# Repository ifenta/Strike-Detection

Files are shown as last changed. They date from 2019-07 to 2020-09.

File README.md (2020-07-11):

# Strike-Detection
Ideally I want to be able to:
- correct different strike and block techniques
- calculate speed of the strikes
- count how many times you do different strikes (flow hitting on a heavy bag for example)

With the camera, I want: 
- correct form now that I can see the whole body and depth
- detect if you are doing a lead or rear punch/kick
- see if I can improve transitions from different techniques

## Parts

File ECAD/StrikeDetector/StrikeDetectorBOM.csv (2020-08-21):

Qty | Value | Device | Package | Parts | Description
1 |  | CP2104-F03-GM | QFN50P400X400X80-25N | U5 | USB-to-UART 1-CH 576byte FIFO 3.3V 24-Pin QFN EP T/R
1 |  | HEADER-1X2ROUND | 1X02_ROUND | JP1 | PIN HEADER
1 |  | HEADER-1X6ROUND | 1X06_ROUND | JP3 | PIN HEADER
1 | 0.22uF | CAP_CERAMIC0603 | 0603 | C2 | Ceramic Capacitors
4 | 100kΩ | RESISTOR0603 | 0603 | R1, R2, R5, R11 | Resistors
1 | 10118193-0001LF | 10118193-0001LF | FCI_10118193-0001LF | J1 | Micro USB B Type Receptacle
2 | 10kΩ | RESISTOR0603 | 0603 | R3, R4 | Resistors
6 | 10uF | CAP_CERAMIC0603 | 0603 | C1, C3, C4, C6, C7, C8 | Ceramic Capacitors
2 | 1kΩ | RESISTOR0603 | 0603 | R9, R10 | Resistors
1 | 1uF | CAP_CERAMIC0603 | 0603 | C5 | Ceramic Capacitors
3 | 4.7kΩ | RESISTOR0603 | 0603 | R6, R7, R8 | Resistors
1 | AP2112K-3.3TRG1 | AP2112K-3.3TRG1 | SOT95P285X140-5N | U6 | AP2112 Series 0.6 A 3.3 V Fixed Output SMT LDO Linear Regulator - SOT23-5
1 | CJS-1200TA | CJS-1200TA | SW_CJS-1200TA | S1 | Switch Slide N.O./N.C. SPDT Raised Slide 0.1A 24VDC J-Hook SMD Embossed T/R
1 | ESP32-WROOM-32 | ESP32-WROOM-32 | MODULE_ESP32-WROOM-32 | U4 | Bluetooth, WiFi Transceiver Module 2.4GHz ~ 2.5GHz Surface Mount
2 | KMR211GLFS | SPST_TACT-KMR2 | KMR2 | SW1, SW2 | SMT 6mm switch, EVQQ2 series
1 | LSM9DS1TR | LSM9DS1TR | PQFN43P300X350X102-24N | U3 | The LSM9DS1 is a system-in-package featuring a
2 | MBR120 | DIODESOD-123 | SOD-123 | D1, D2 | Diode
1 | MCP73831T-2ACI/OT | MCP73831T-2ACI/OT | SOT95P280X145-5N | U$1 | Charge Management Controller
2 | MMBT2222A-7-F | MMBT2222A-7-F | SOT103P240X110-3N | U1, U2 | NPN SMALL SIGNAL SURFACE MOUNT TRANSISTOR
1 | ORANGE | LED0603 | CHIPLED_0603 | LED2 | LED
1 | RED | LED0603 | CHIPLED_0603 | LED1 | LED

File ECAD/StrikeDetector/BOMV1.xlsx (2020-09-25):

Designator | MPN | Qty | Link
C1, C3, C4, C6, C7, C8 | LMK107BBJ106MALT | 6 | https://www.digikey.com/product-detail/en/taiyo-yuden/LMK107BBJ106MALT/587-3258-1-ND/3662218
C2 | CC0603KRX7R7BB224 | 1 | https://www.digikey.com/product-detail/en/yageo/CC0603KRX7R7BB224/311-1426-1-ND/2833732
C5 | CL10B105MO8NNWC | 1 | https://www.digikey.com/product-detail/en/samsung-electro-mechanics/CL10B105MO8NNWC/1276-6524-1-ND/5961383
D1, D2 | MBR120ESFT3G | 2 | https://www.digikey.com/product-detail/en/on-semiconductor/MBR120ESFT3G/MBR120ESFT3GOSCT-ND/5969071
J1 | 10118193-0001LF | 1 | https://www.digikey.com/product-detail/en/amphenol-icc-fci/10118193-0001LF/609-4616-1-ND/2785380
LED1 | 150060RS75000 | 1 | https://www.digikey.com/product-detail/en/w%C3%BCrth-elektronik/150060RS75000/732-4978-1-ND/4489899
LED2 | 150060YS75000 | 1 | https://www.digikey.com/product-detail/en/w%C3%BCrth-elektronik/150060YS75000/732-4981-1-ND/4489907
R1, R2, R5, R11 | RMCF0603FT100K | 4 | https://www.digikey.com/product-detail/en/stackpole-electronics-inc/RMCF0603FT100K/RMCF0603FT100KCT-ND/1943118
R3, R4, R6, R7, R8, R12, R13, R14, R15, R16 | RC0603FR-0710KL | 10 | https://www.digikey.com/product-detail/en/yageo/RC0603FR-0710KL/311-10-0KHRCT-ND/729827
R9, R10 | RC0603FR-071KL | 2 | https://www.digikey.com/product-detail/en/yageo/RC0603FR-071KL/311-1-00KHRCT-ND/729790
S1 | CJS-1200TA | 1 | https://www.digikey.com/product-detail/en/nidec-copal-electronics/CJS-1200TA/563-1021-1-ND/948401
SW1, SW2 | KMR211GLFS | 2 | https://www.digikey.com/product-detail/en/c-k/KMR211GLFS/401-1426-1-ND/550461
U$1 | MCP73831T-2ACI/OT | 1 | https://www.digikey.com/product-detail/en/microchip-technology/MCP73831T-2ACI-OT/MCP73831T-2ACI-OTCT-ND/1979802
U1, U2 | MMBT2222A-7-F | 2 | https://www.digikey.com/product-detail/en/diodes-incorporated/MMBT2222A-7-F/MMBT2222A-FDICT-ND/815723
U3 | LSM9DS1TR | 1 | https://www.digikey.com/product-detail/en/stmicroelectronics/LSM9DS1TR/497-14946-1-ND/4988079
U4 | ESP32-WROOM-32 | 1 | https://www.digikey.com/product-detail/en/espressif-systems/ESP32-WROOM-32/1904-1010-1-ND/8544305
U5 | CP2104-F03-GMR | 1 | https://www.digikey.com/product-detail/en/silicon-labs/CP2104-F03-GMR/336-4146-1-ND/7650425
U6 | AP2112K-3.3TRG1 | 1 | https://www.digikey.com/product-detail/en/diodes-incorporated/AP2112K-3-3TRG1/AP2112K-3-3TRG1DICT-ND/4505257

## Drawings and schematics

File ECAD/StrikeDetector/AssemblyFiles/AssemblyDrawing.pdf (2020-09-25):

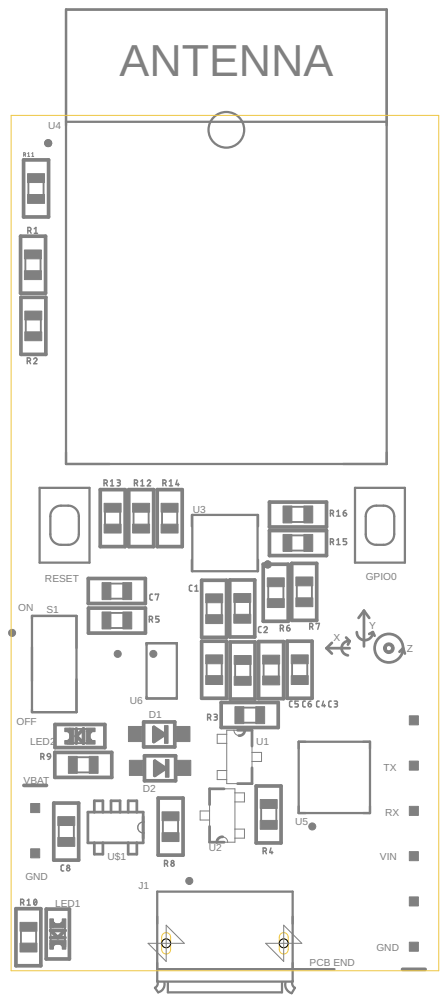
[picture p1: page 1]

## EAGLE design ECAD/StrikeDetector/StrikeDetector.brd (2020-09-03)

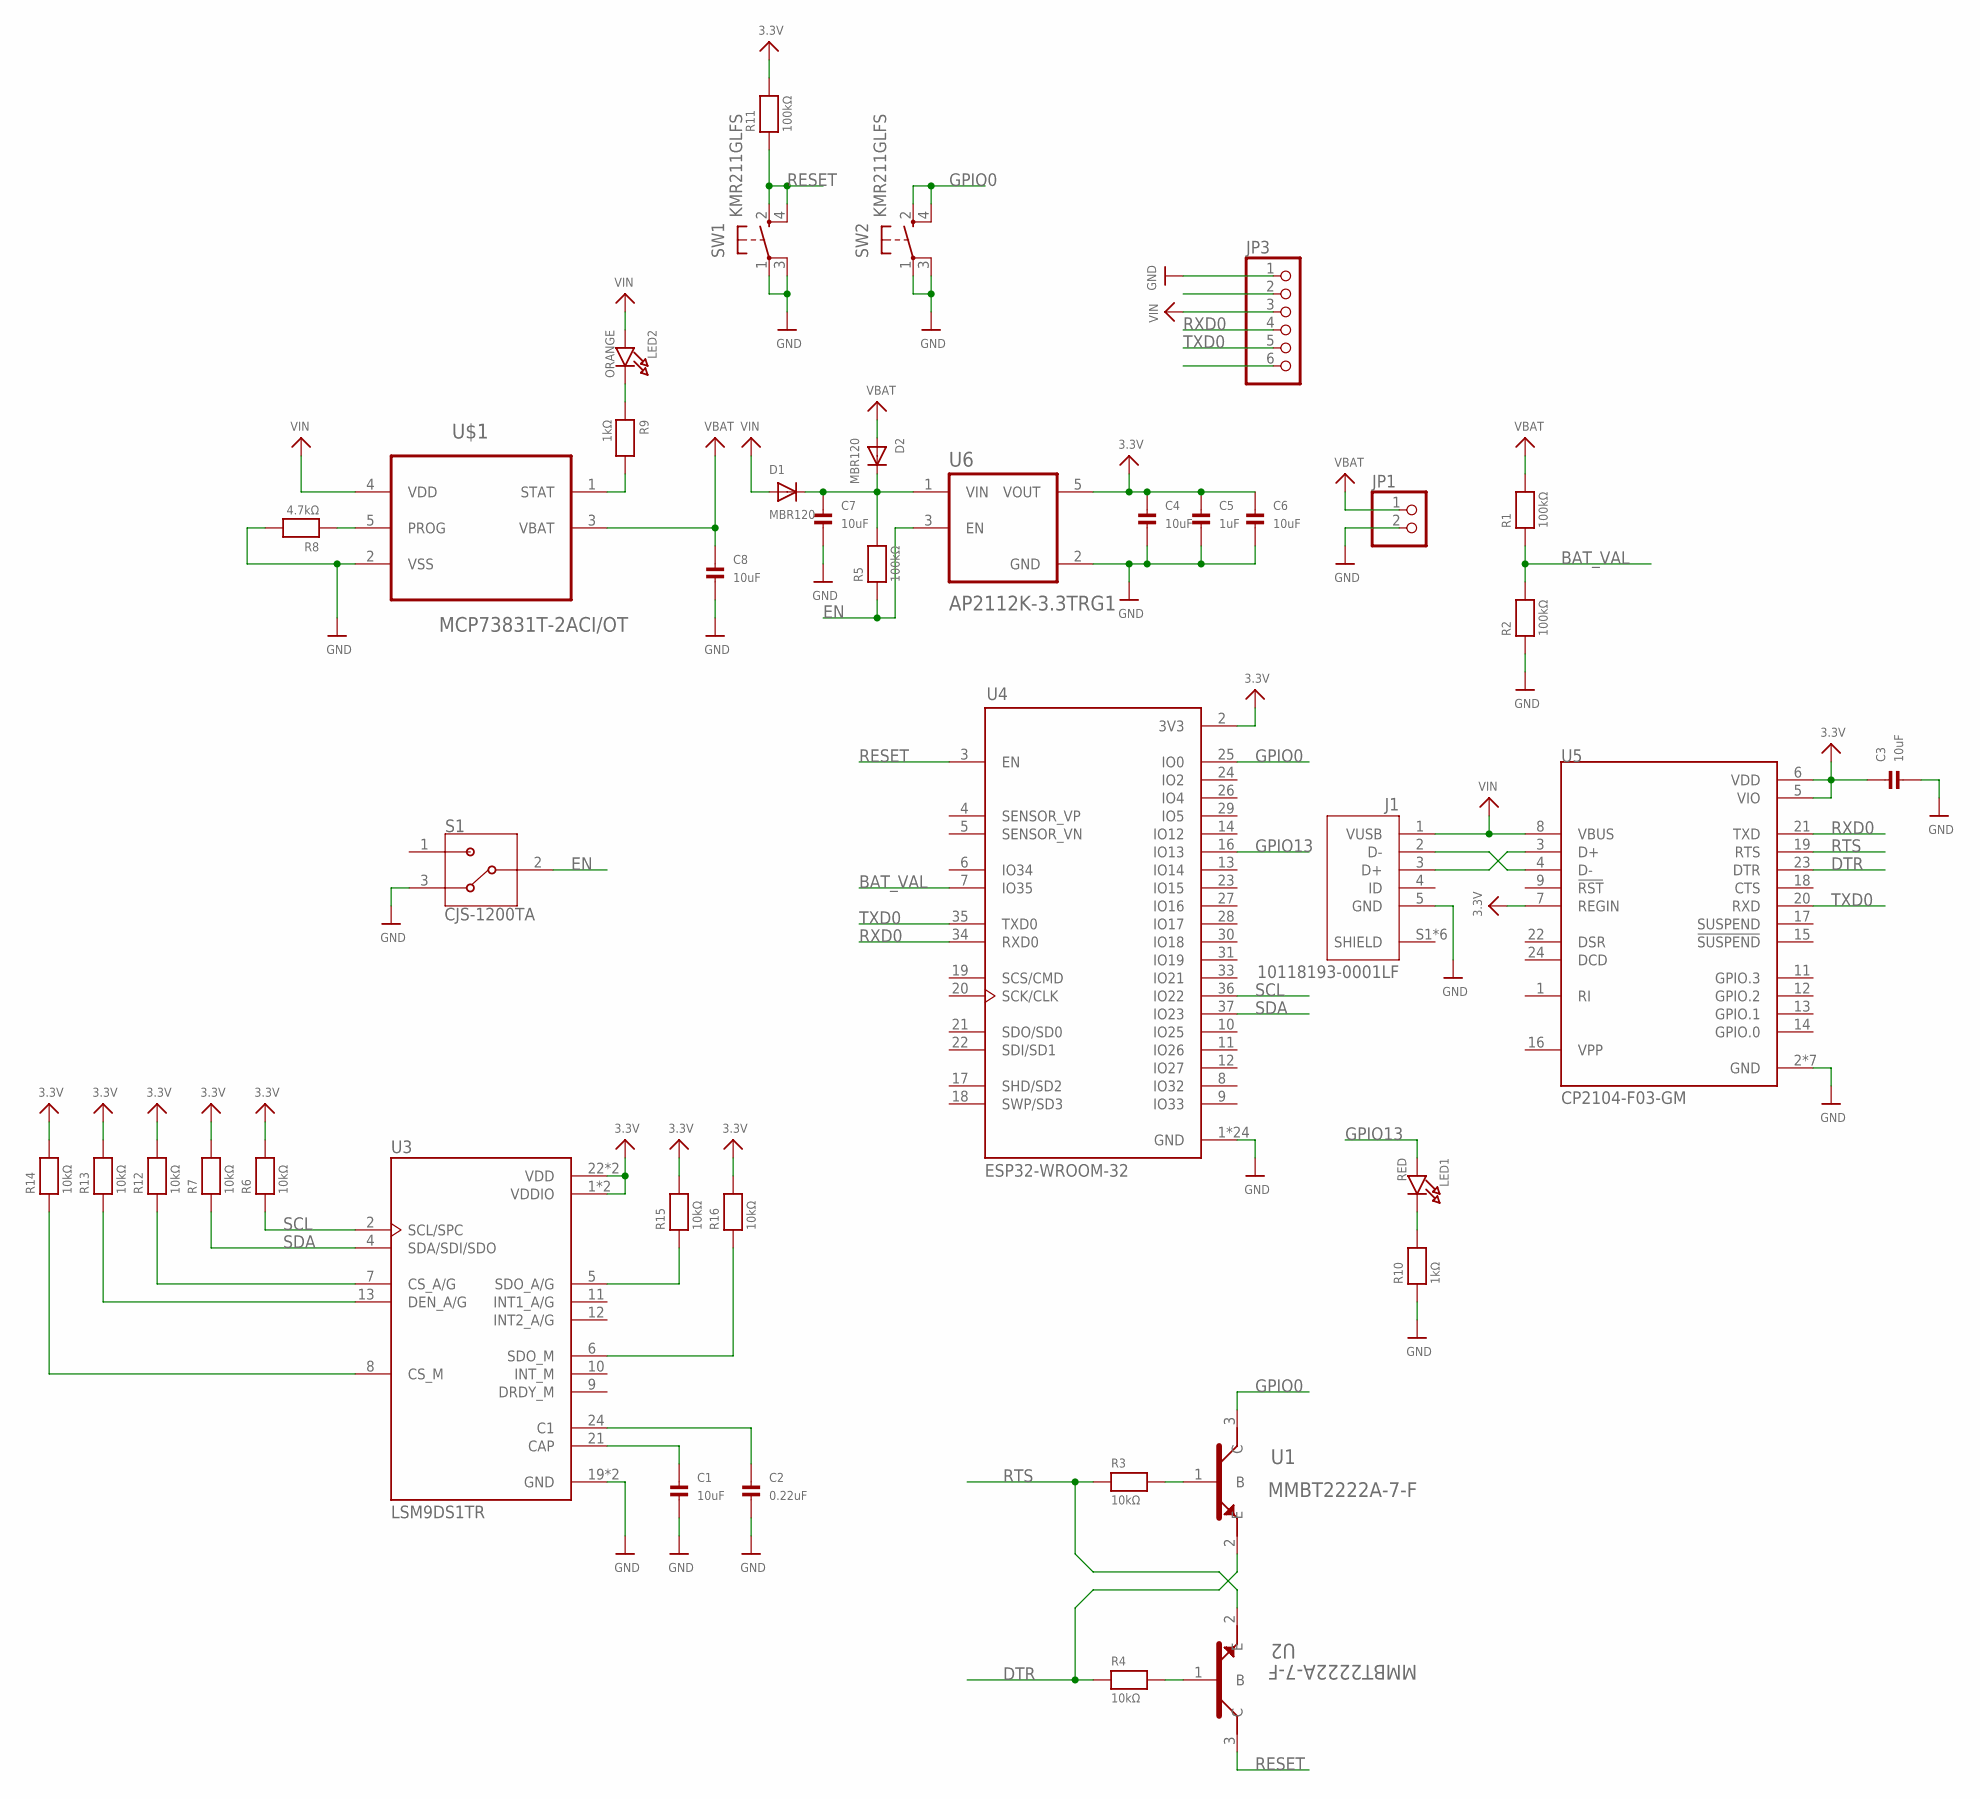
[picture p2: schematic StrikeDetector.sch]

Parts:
C1, C3, C4, C6, C7, C8: 10uF; 0603
C2: 0.22uF; 0603
C5: 1uF; 0603
D1, D2: MBR120; SOD-123
J1: 10118193-0001LF; FCI_10118193-0001LF
JP1: HEADER-1X2ROUND; 1X02_ROUND
JP3: HEADER-1X6ROUND; 1X06_ROUND
LED1: RED; CHIPLED_0603
LED2: ORANGE; CHIPLED_0603
R1, R2, R5, R11: 100kΩ; 0603
R3, R4, R6, R7, R12, R13, R14, R15, R16: 10kΩ; 0603
R8: 4.7kΩ; 0603
R9, R10: 1kΩ; 0603
S1: CJS-1200TA; SW_CJS-1200TA
SW1, SW2: KMR211GLFS; KMR2
U1, U2: MMBT2222A-7-F; SOT103P240X110-3N
U3: LSM9DS1TR; PQFN43P300X350X102-24N
U4: ESP32-WROOM-32; MODULE_ESP32-WROOM-32
U5: CP2104-F03-GM; QFN50P400X400X80-25N
U6: AP2112K-3.3TRG1; SOT95P285X140-5N
U$1: MCP73831T-2ACI/OT; SOT95P280X145-5N

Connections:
3.3V: C3.1, C4.1, C5.1, C6.1, R6.2, R7.2, R11.2, R12.2, R13.2, R14.2, R15.2, R16.2, U3.1 (VDDIO), U3.3 (VDDIO), U3.22 (VDD), U3.23 (VDD), U4.2 (3V3), U5.5 (VIO), U5.6 (VDD), U5.7 (REGIN), U6.5 (VOUT)
BAT_VAL: R1.1, R2.2, U4.7 (IO35)
DTR: R4.1, U1.2 (E), U5.23 (DTR)
EN: R5.1, S1.2, U6.3 (EN)
GND: C1.2, C2.2, C3.2, C4.2, C5.2, C6.2, C7.2, C8.2, J1.5 (GND), JP1.2, JP3.1, R2.1, R8.2, R10.1, S1.3, SW1.1, SW1.3 (P1), SW2.1, SW2.3 (P1), U3.19 (GND), U3.20 (GND), U4.1 (GND), U4.15 (GND), U4.38 (GND), U4.39_1 (GND), U4.39_2 (GND), U4.39_3 (GND), U4.39_4 (GND), U4.39_5 (GND), U4.39_6 (GND), U4.39_7 (GND), U4.39_8 (GND), U4.39_9 (GND), U4.39_10 (GND), U4.39_11 (GND), U4.39_12 (GND), U4.39_13 (GND), U4.39_14 (GND), U4.39_15 (GND), U4.39_16 (GND), U4.39_17 (GND), U4.39_18 (GND), U4.39_19 (GND), U4.39_20 (GND), U4.39_21 (GND), U5.2 (GND), U5.25 (GND), U5.THERM_1 (GND), U5.THERM_2 (GND), U5.THERM_3 (GND), U5.THERM_4 (GND), U5.THERM_5 (GND), U6.2 (GND), U$1.2 (VSS)
GPIO0: SW2.2 (S), SW2.4 (S1), U1.3 (C), U4.25 (IO0)
GPIO13: LED1.A, U4.16 (IO13)
unnamed: C1.1, U3.21 (CAP)
unnamed: J1.3 (D+), U5.3 (D+)
unnamed: J1.2 (D-), U5.4 (D-)
unnamed: C2.1, U3.24 (C1)
unnamed: R3.2, U1.1 (B)
unnamed: R4.2, U2.1 (B)
unnamed: C7.1, D1.C, D2.C, R5.2, U6.1 (VIN)
unnamed: R8.1, U$1.5 (PROG)
unnamed: R9.2, U$1.1 (STAT)
unnamed: LED2.C, R9.1
unnamed: LED1.C, R10.2
unnamed: R12.1, U3.7 (CS_A/G)
unnamed: R13.1, U3.13 (DEN_A/G)
unnamed: R14.1, U3.8 (CS_M)
unnamed: R15.1, U3.5 (SDO_A/G)
unnamed: R16.1, U3.6 (SDO_M)
RESET: R11.1, SW1.2 (S), SW1.4 (S1), U2.3 (C), U4.3 (EN)
RTS: R3.1, U2.2 (E), U5.19 (RTS)
RXD0: JP3.4, U4.34 (RXD0), U5.21 (TXD)
SCL: R6.1, U3.2 (SCL/SPC), U4.36 (IO22)
SDA: R7.1, U3.4 (SDA/SDI/SDO), U4.37 (IO23)
TXD0: JP3.5, U4.35 (TXD0), U5.20 (RXD)
VBAT: C8.1, D2.A, JP1.1, R1.2, U$1.3 (VBAT)
VIN: D1.A, J1.1 (VUSB), JP3.3, LED2.A, U5.8 (VBUS), U$1.4 (VDD)

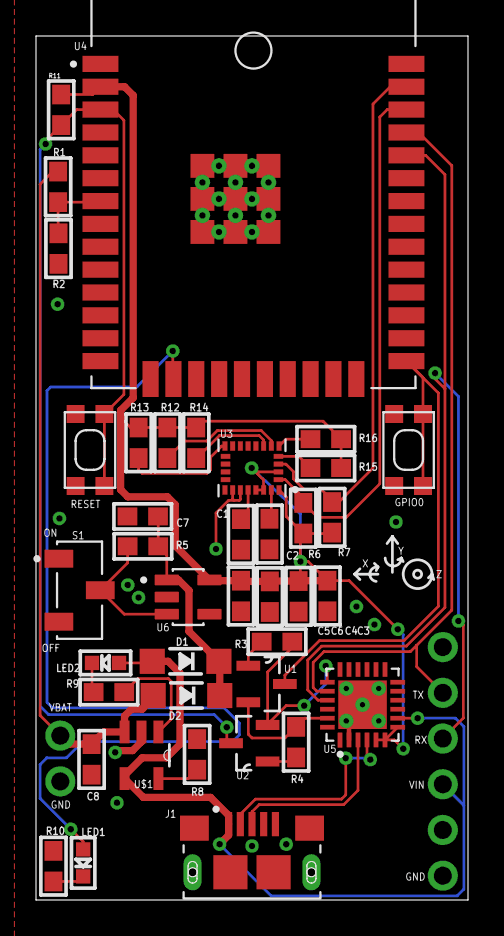
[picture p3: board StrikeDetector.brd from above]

Board: 2 copper layers, 24.0 x 48.0 mm, 41 parts (0 on the bottom side), 31 nets.

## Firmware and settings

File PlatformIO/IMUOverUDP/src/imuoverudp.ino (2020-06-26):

#include <Arduino.h>

#include <WiFi.h>
#include "AsyncUDP.h"

#include <Wire.h>
#include <Adafruit_LSM9DS1.h>
#include <Adafruit_Sensor.h>  // not used in this demo but required!

#define LED_PIN 0
#define IGNORE_TIME 30  //ms
#define READ_TIME 15000 //ms

// i2c
Adafruit_LSM9DS1 lsm = Adafruit_LSM9DS1();

unsigned long timer;

const char * ssid = "********";
const char * password = "********";

AsyncUDP udp;

// Check to make sure the IP address of the computer on the router is this
IPAddress ip = IPAddress(192,168,0,108);
int portNum = 9999;

bool connected = false;

void setupSensor(){
  // Set the accelerometer range

  lsm.setupAccel(lsm.LSM9DS1_ACCELRANGE_16G);
  
  // Set the magnetometer sensitivity
  lsm.setupMag(lsm.LSM9DS1_MAGGAIN_16GAUSS);

  // Setup the gyroscope
  lsm.setupGyro(lsm.LSM9DS1_GYROSCALE_2000DPS);
}

void setup()
{
    Serial.begin(115200);

    pinMode(LED_PIN, OUTPUT);

    digitalWrite(LED_PIN, HIGH);
    
    // Try to initialise and warn if we couldn't detect the chip
    if (!lsm.begin())
    {
      Serial.println("Oops ... unable to initialize the LSM9DS1. Check your wiring!");
      while(1){
        delay(1000);
      }
    }
    Serial.println("Found LSM9DS1 9DOF");

    // helper to just set the default scaling we want, see above!
    setupSensor();

    WiFi.mode(WIFI_STA);
    WiFi.begin(ssid, password);
    if (WiFi.waitForConnectResult() != WL_CONNECTED) {
        Serial.println("WiFi Failed");
        while(1) {
            delay(1000);
        }
    }
    Serial.println("Wifi connected!");
    Serial.print("IP Address: ");
    Serial.println(WiFi.localIP());

    if(udp.connect(ip, portNum)) {
        Serial.println("UDP connected");
        udp.onPacket([](AsyncUDPPacket packet) {
            Serial.println("Message Recieved");
            connected = true;
        });
    }

    while(!connected){
      udp.broadcastTo("Hello\n", portNum);
      delay(2000);
    }
    Serial.println("UDP Ack Recieved");
    // Initilize csv file
    String message = "Time(ms);AccX(m/s^2);AccY(m/s^2);AccZ(m/s^2);MagX(gauss);MagY(gauss);MagZ(gauss);GyroX(dps);GyroY(dps);GyroZ(dps)\n";
    udp.broadcastTo(message.c_str(), portNum);
    Serial.println("Send Intial message");
    // Start timer
    timer = millis();

}

void loop()
{

    Serial.println("Loop Begin");

    digitalWrite(LED_PIN, LOW);
    while(1){
        if((millis()-timer)<READ_TIME){
          lsm.read();  /* ask it to read in the data */ 
        
          /* Get a new sensor event */ 
          sensors_event_t a, m, g, temp;
          lsm.getEvent(&a, &m, &g, &temp); 

          // Wait 30 millis to read to get rid of initialization data
          if(millis()-timer>IGNORE_TIME){
              String message;
              // Timestamp
              message += String(millis()-timer) + ";";
            
              // Acceleration Data
              message += String(a.acceleration.x) + ";";
              message += String(a.acceleration.y) + ";";
              message += String(a.acceleration.z) + ";";
            
              // Magnetometer Data
              message += String(m.magnetic.x) + ";";
              message += String(m.magnetic.y) + ";";
              message += String(m.magnetic.z) + ";";
            
              // Gyroscope Data
              message += String(g.gyro.x) + ";";
              message += String(g.gyro.y) + ";";
              message += String(g.gyro.x) + "\n";

              // Send over UDP
              udp.broadcastTo(message.c_str(), portNum);
        }
      }else{
        // Send complete to say we are done recording
        String message = "complete\n";
        udp.broadcastTo(message.c_str(), portNum);

        Serial.println("complete");
        // Turn off light and stop recording
        digitalWrite(LED_PIN, HIGH);
        while(1){
          delay(1000);
        }
      }  
      delay(1);
  }  
}

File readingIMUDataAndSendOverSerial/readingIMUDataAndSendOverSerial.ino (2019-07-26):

#include <Wire.h>
#include <SPI.h>
#include <Adafruit_LSM9DS1.h>
#include <Adafruit_Sensor.h>  // not used in this demo but required!

// i2c
Adafruit_LSM9DS1 lsm = Adafruit_LSM9DS1();

#define LSM9DS1_SCK A5
#define LSM9DS1_MISO 12
#define LSM9DS1_MOSI A4
#define LSM9DS1_XGCS 6
#define LSM9DS1_MCS 5
// You can also use software SPI
//Adafruit_LSM9DS1 lsm = Adafruit_LSM9DS1(LSM9DS1_SCK, LSM9DS1_MISO, LSM9DS1_MOSI, LSM9DS1_XGCS, LSM9DS1_MCS);
// Or hardware SPI! In this case, only CS pins are passed in
//Adafruit_LSM9DS1 lsm = Adafruit_LSM9DS1(LSM9DS1_XGCS, LSM9DS1_MCS);

int x = 0;

float data[3][3];

unsigned long timer;

void setupSensor()
{
  // 1.) Set the accelerometer range
  //lsm.setupAccel(lsm.LSM9DS1_ACCELRANGE_2G);
  //lsm.setupAccel(lsm.LSM9DS1_ACCELRANGE_4G);
  //lsm.setupAccel(lsm.LSM9DS1_ACCELRANGE_8G);
  lsm.setupAccel(lsm.LSM9DS1_ACCELRANGE_16G);
  
  // 2.) Set the magnetometer sensitivity
  //lsm.setupMag(lsm.LSM9DS1_MAGGAIN_4GAUSS);
  //lsm.setupMag(lsm.LSM9DS1_MAGGAIN_8GAUSS);
  //lsm.setupMag(lsm.LSM9DS1_MAGGAIN_12GAUSS);
  lsm.setupMag(lsm.LSM9DS1_MAGGAIN_16GAUSS);

  // 3.) Setup the gyroscope
  //lsm.setupGyro(lsm.LSM9DS1_GYROSCALE_245DPS);
  //lsm.setupGyro(lsm.LSM9DS1_GYROSCALE_500DPS);
  lsm.setupGyro(lsm.LSM9DS1_GYROSCALE_2000DPS);
}

void zeroArray(){
  for(int i=0; i<3; i++){
    for(int j=0; j<3; j++){
      data[i][j]=0;
    }
  }
}

void averageArray(){
  for(int i=0; i<3; i++){
    for(int j=0; j<3; j++){
      data[i][j]/=10;
    }
  }
}

void setup() 
{
  pinMode(13, OUTPUT);
  digitalWrite(13, LOW);
  Serial.begin(115200);

  while (!Serial) {
    delay(1); // will pause Zero, Leonardo, etc until serial console opens
  }
  digitalWrite(13, HIGH);
  
  //Serial.println("LSM9DS1 data read demo");
  
  // Try to initialise and warn if we couldn't detect the chip
  if (!lsm.begin())
  {
    Serial.println("Oops ... unable to initialize the LSM9DS1. Check your wiring!");
    while (1);
  }
  //Serial.println("Found LSM9DS1 9DOF");

  // helper to just set the default scaling we want, see above!
  setupSensor();

  zeroArray();
  Serial.println("Time(ms);AccX(m/s^2);AccY(m/s^2);AccZ(m/s^2);MagX(gauss);MagY(gauss);MagZ(gauss);GyroX(dps);GyroY(dps);GyroZ(dps)");
  timer = millis();
}

void loop() 
{
  if((millis()-timer)<15000){
    lsm.read();  /* ask it to read in the data */ 
  
    /* Get a new sensor event */ 
    sensors_event_t a, m, g, temp;
  
    lsm.getEvent(&a, &m, &g, &temp); 

    if(millis()-timer>30){
      Serial.print(millis()-timer); Serial.print(";");
    
      Serial.print(a.acceleration.x); Serial.print(";");
      Serial.print(a.acceleration.y); Serial.print(";");
      Serial.print(a.acceleration.z); Serial.print(";");
    
      Serial.print(m.magnetic.x); Serial.print(";");
      Serial.print(m.magnetic.y); Serial.print(";");
      Serial.print(m.magnetic.z); Serial.print(";");
    
      Serial.print(g.gyro.x); Serial.print(";");
      Serial.print(g.gyro.y); Serial.print(";");
      Serial.println(g.gyro.z); 
    }
  }else{
    Serial.println("complete");
    digitalWrite(13, LOW);
    while(1);
  }
  
}

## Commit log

2020-02-17 Organizing
    Tranfering Arduino code to PlatformIO
    Organizing folders
2020-02-18 Sending Data Over Wifi
    Did a bit of organizing of files
    Able to send IMU data over UDP to my computer and run the python script to determine what kind of punch it is. Need to work a bit more on the analysis and how to incorporate it together with the rest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
2020-07-11 Working Live Algorithm
    - Data is updated live and algorithm works okay
    - Need to attach device to arm, and update code to read the correct directions
    [streamimu.ino]
2020-07-11 Working Strike Detection
    Added check on gyroY to check twist to make it more accurate
2020-07-11 Auto reconnect
    - Added auto reconnect on the esp32 if it gets disconnected
    - send ack to esp32 every 3 sec
2020-07-14 Tested TCP Server
    - Tested TCP server and it was too slow to keep up with the live data
    - Organized the code a bit
    [streamimu.ino]
2020-07-16 Tried TCP and everything broke
    [streamimu.ino]
2020-07-16 Revert back to working days
    [streamimu.ino]
2020-07-16 Revert "Revert back to working days"
    This reverts commit a13b234cb50495ef2fe12cd30969025bcb449abe.
    [streamimu.ino]
2020-07-16 Beginning to make 4 threads for the different connections
2020-08-12 Created ECAD schematic
    [StrikeDetector.sch]
2020-08-19 Finished Preliminary PCB Design
    [StrikeDetector.brd]
2020-08-19 Added dimension
    [StrikeDetector.brd]
2020-08-20 Updated PCB Design
    [StrikeDetector.brd, StrikeDetector.sch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]
2020-08-21 Updated board files
    [StrikeDetectorBOM.csv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]
2020-09-03 Updated ECAD
    Added Pull up resistors for the pins I was missing
    [StrikeDetector.brd, StrikeDetector.sch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]
2020-09-25 Updating ecad stuff
    [BOMV1.xlsx, StrikeDetector_centroid.csv]
2021-03-25 Update
    Added modification to save data to be processed in tensorflow
    [strike_data_for_ml.csv]

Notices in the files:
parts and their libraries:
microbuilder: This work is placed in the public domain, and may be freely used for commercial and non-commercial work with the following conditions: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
